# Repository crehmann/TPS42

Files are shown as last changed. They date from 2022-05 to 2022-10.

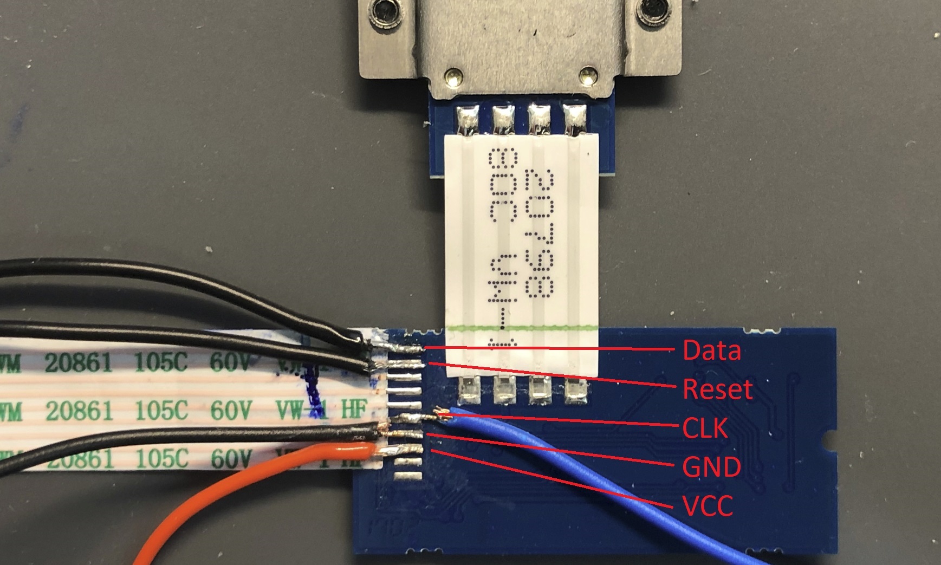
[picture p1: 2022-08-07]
Assets/trackpoint_wiring.jpg

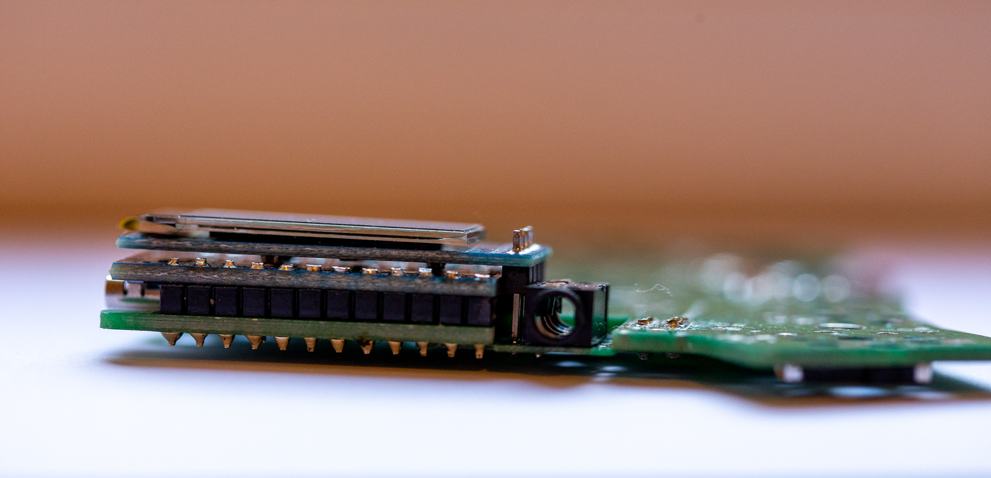
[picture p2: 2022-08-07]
Assets/wired_pcb_side.jpg

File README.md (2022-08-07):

# TPS42

TPS42 is a 42/36 keys ergonomic split keyboard. The outer pinky columns can be broken off. The main goal for desing it was to have a low profile split keyboard with an integrated TrackPoint module

## Features
- Integrated TrackPoint reset circuit and the option to mount a TrackPoint to the bottom of the PCB (between the two inner columns)
- I2C interface for an OLED display
- Wireless Ready (however, without TrackPoint support):
  - Battery switch / connector
  - Option to use a battery friendly Sharp memory display instead of an OLED display
- Choc-spaced
- Partially hot swap sockets supported (except for two switches around the TrackPoint module)

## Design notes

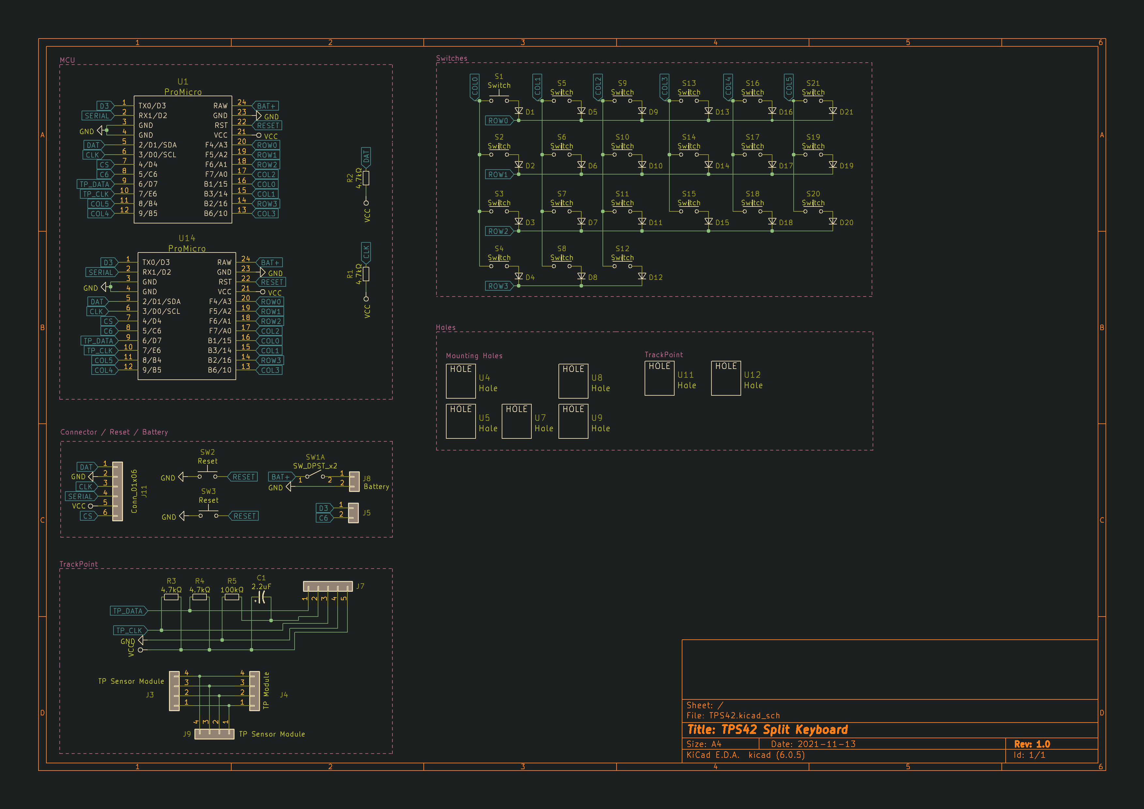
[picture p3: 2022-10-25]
Assets/schematic.png

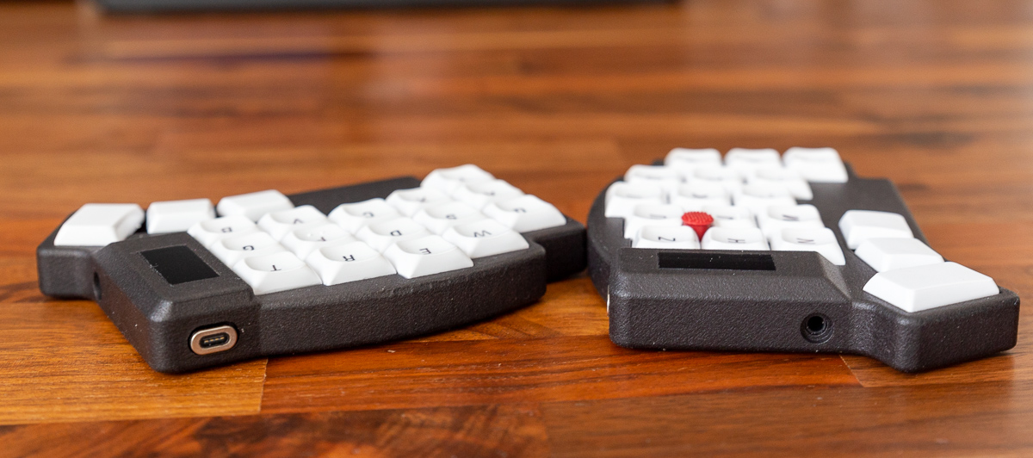
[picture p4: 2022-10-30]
Assets/wired_case_side.jpg

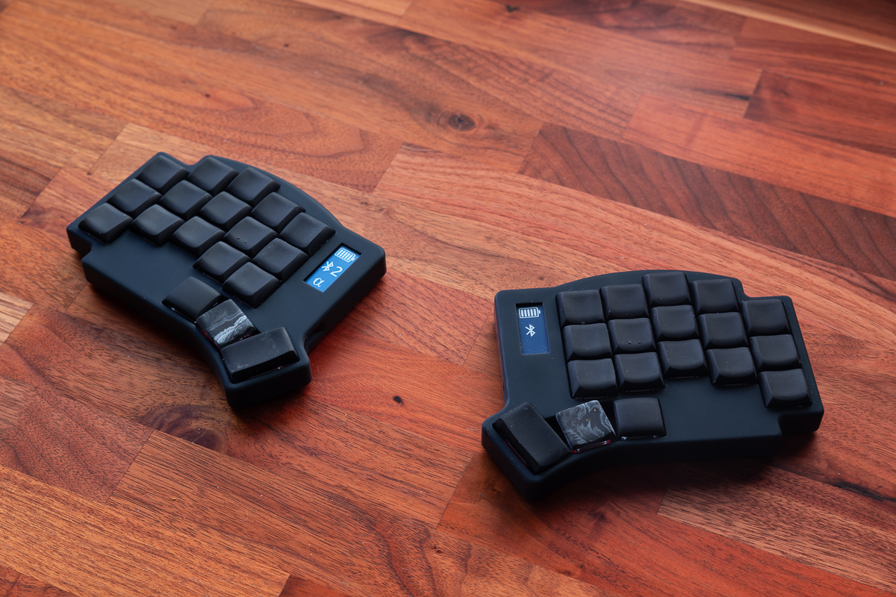
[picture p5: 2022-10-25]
Assets/wireless_case_top2.jpg

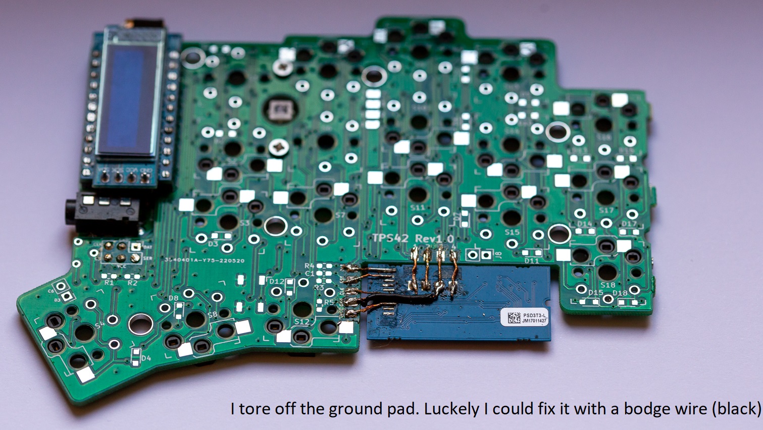
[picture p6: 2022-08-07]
Assets/wired_pcb_front.jpg

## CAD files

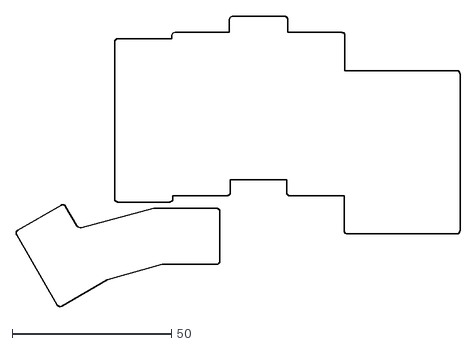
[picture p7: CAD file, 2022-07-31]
Case/3dp/outlines/keycaps_outline_3x6.dxf
139.3 x 91.2

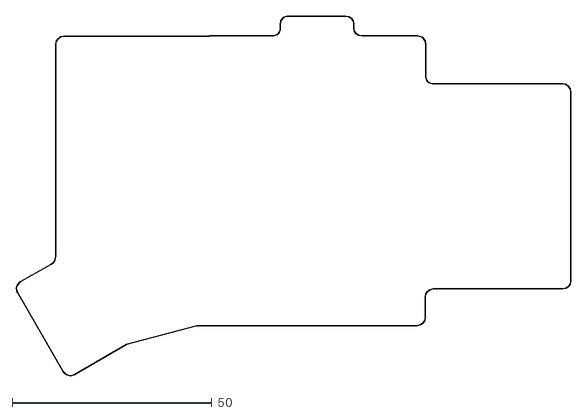
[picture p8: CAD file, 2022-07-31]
Case/3dp/outlines/pcb_outline_3x6.dxf
139.0 x 90.2

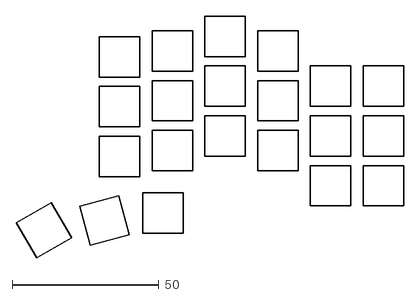
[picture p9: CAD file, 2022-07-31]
Case/3dp/outlines/switch_outline_3x6.dxf
132.1 x 82.5

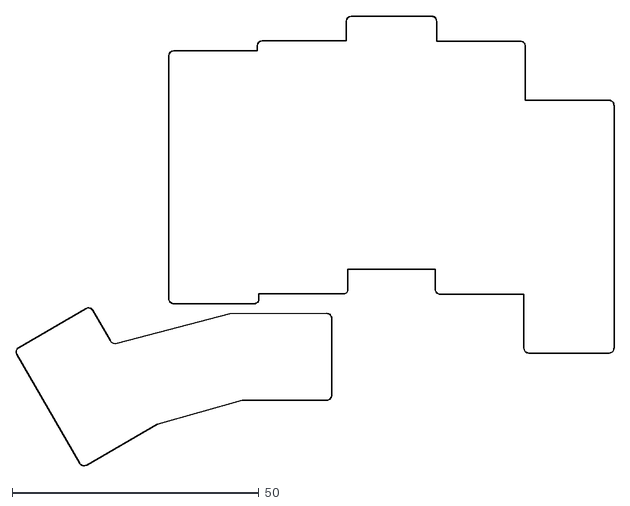
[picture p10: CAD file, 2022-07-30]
Case/3dp/outlines/keycaps_outline.dxf
121.2 x 91.2

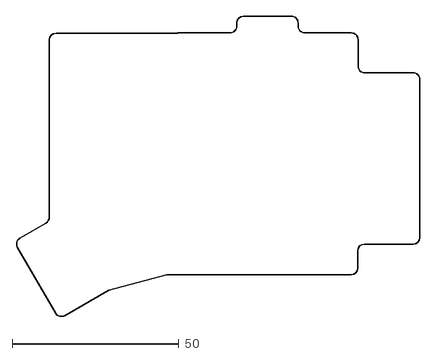
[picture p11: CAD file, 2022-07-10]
Case/3dp/outlines/pcb_outline.dxf
121.1 x 90.2

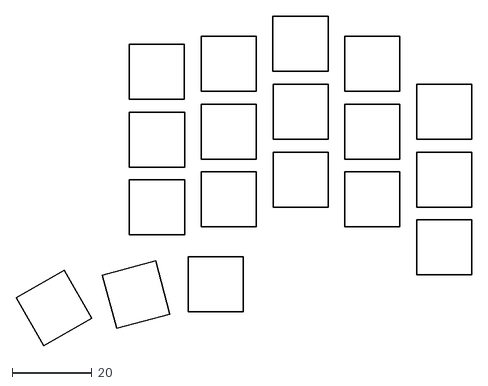
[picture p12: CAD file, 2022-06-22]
Case/3dp/outlines/switch_outline.dxf
114.2 x 82.5

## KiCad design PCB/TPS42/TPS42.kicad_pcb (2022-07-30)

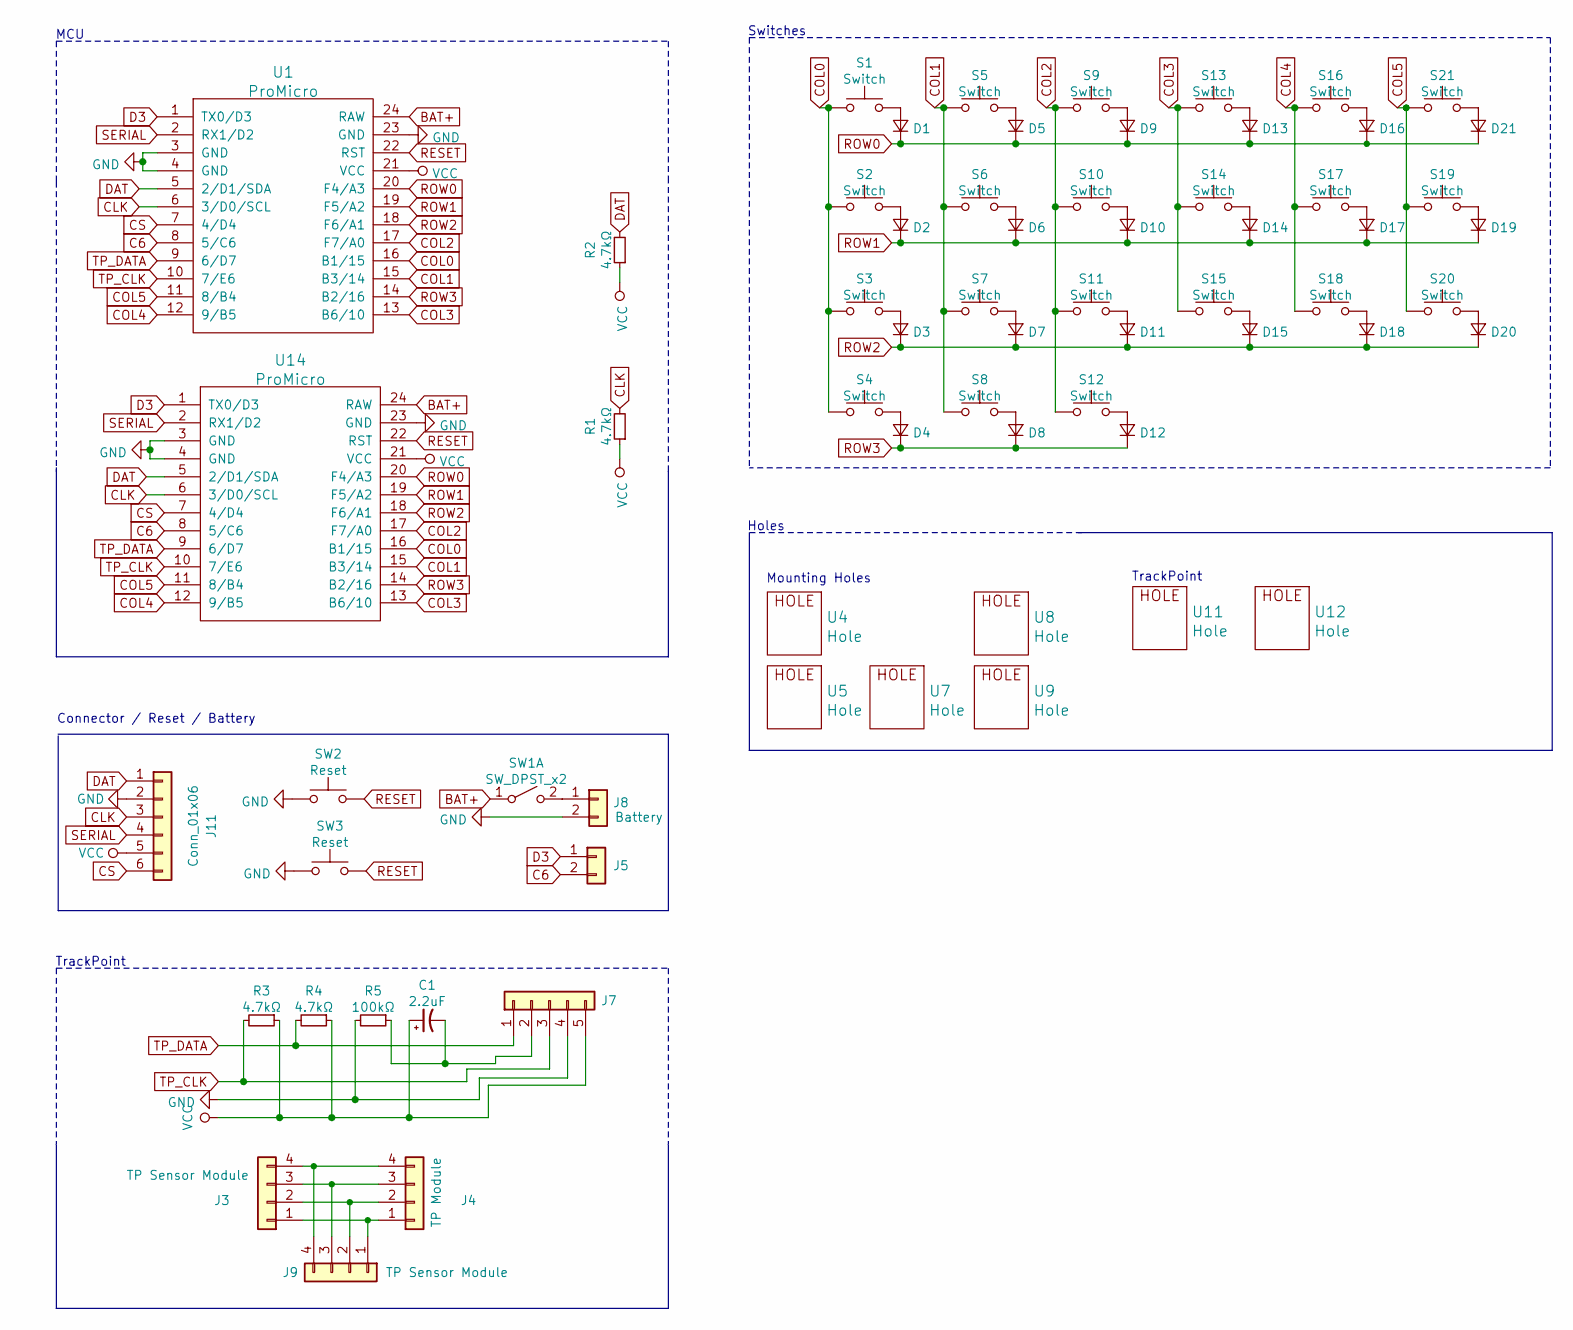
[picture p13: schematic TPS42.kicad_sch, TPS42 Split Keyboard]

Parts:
C1: 2.2uF; C_0603_1608Metric_Pad1.08x0.95mm_HandSolder_Reversable
D1, D2, D3, D4, D5, D6, D7, D8, D9, D10, D11, D12, D13, D14, D15, D16, D17, D18, D19, D20, D21: D_Small; D_SOD-323_HandSoldering_Reversable
J3, J9: TP Sensor Module; TPSensorModule_Connector
J4: TP Module; TPSensorModule_Connector
J5: Conn_01x02; PinHeader_1x02_P2.54mm_Vertical
J7: TrackPoint; TPModule
J8: Battery; PinHeader_1x02_P2.54mm_Vertical
J11: Conn_01x06; PinHeader_2x03_P2.54mm_Vertical
R1, R2, R3, R4: 4.7kΩ; R_0603_1608Metric_Pad0.98x0.95mm_HandSolder_Reversable
R5: 100kΩ; R_0603_1608Metric_Pad0.98x0.95mm_HandSolder_Reversable
S1, S6: Switch; SW_PG1350_reversible
S2, S3, S5, S7, S8, S9, S10, S11, S12, S13, S14, S15, S16, S17, S18, S19, S20, S21: Switch; Kailh_socket_PG1350_optional_reversible.kicad_mod
S4: Switch; Kailh_socket_PG1350_125_optional_reversible.kicad_mod
SW1: SW_DPST_x2; SW-TH_3P-L9.1-W3.5-P2.50-S3.20-A3
SW2, SW3: Reset; SMD-SW-4_5.1x5.1x2.5
U1: ProMicro; ProMicro_Flipped_v2_A
U4, U5, U7, U8, U9, U12: Hole; HOLE_M2_TH
U11: Hole; TPSensorModule
U14: ProMicro; ProMicro_Flipped_v2_B

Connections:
BAT+: SW1.1 (A), U1.24 (RAW), U14.24 (RAW)
C6: J5.2, U1.8 (5/C6), U14.8 (5/C6)
CLK: J11.3, R1.2, U1.6 (3/D0/SCL), U14.6 (3/D0/SCL)
COL0: S1.1, S2.1, S3.1, S4.1, U1.16 (B1/15), U14.16 (B1/15)
COL1: S5.1, S6.1, S7.1, S8.1, U1.15 (B3/14), U14.15 (B3/14)
COL2: S9.1, S10.1, S11.1, S12.1, U1.17 (F7/A0), U14.17 (F7/A0)
COL3: S13.1, S14.1, S15.1, U1.13 (B6/10), U14.13 (B6/10)
COL4: S16.1, S17.1, S18.1, U1.12 (9/B5), U14.12 (9/B5)
COL5: S19.1, S20.1, S21.1, U1.11 (8/B4), U14.11 (8/B4)
CS: J11.6, U1.7 (4/D4), U14.7 (4/D4)
D3: J5.1, U1.1 (TX0/D3), U14.1 (TX0/D3)
DAT: J11.1, R2.2, U1.5 (2/D1/SDA), U14.5 (2/D1/SDA)
GND: J7.4, J8.2, J11.2, R5.2, SW2.1, SW3.1, U1.3 (GND), U1.4 (GND), U1.23 (GND), U14.3 (GND), U14.4 (GND), U14.23 (GND)
unnamed: C1.2, J7.2, R5.1
unnamed: D1.2 (A), S1.2
unnamed: D2.2 (A), S2.2
unnamed: D3.2 (A), S3.2
unnamed: D4.2 (A), S4.2
unnamed: D5.2 (A), S5.2
unnamed: D6.2 (A), S6.2
unnamed: D7.2 (A), S7.2
unnamed: D8.2 (A), S8.2
unnamed: D9.2 (A), S9.2
unnamed: D10.2 (A), S10.2
unnamed: D11.2 (A), S11.2
unnamed: D12.2 (A), S12.2
unnamed: D13.2 (A), S13.2
unnamed: D14.2 (A), S14.2
unnamed: D15.2 (A), S15.2
unnamed: D16.2 (A), S16.2
unnamed: D17.2 (A), S17.2
unnamed: D18.2 (A), S18.2
unnamed: D19.2 (A), S19.2
unnamed: D20.2 (A), S20.2
unnamed: D21.2 (A), S21.2
unnamed: J3.1, J4.1, J9.1
unnamed: J3.2, J4.2, J9.2
unnamed: J3.3, J4.3, J9.3
unnamed: J3.4, J4.4, J9.4
unnamed: J8.1, SW1.2 (B)
RESET: SW2.2, SW3.2, U1.22 (RST), U14.22 (RST)
ROW0: D1.1 (K), D5.1 (K), D9.1 (K), D13.1 (K), D16.1 (K), D21.1 (K), U1.20 (F4/A3), U14.20 (F4/A3)
ROW1: D2.1 (K), D6.1 (K), D10.1 (K), D14.1 (K), D17.1 (K), D19.1 (K), U1.19 (F5/A2), U14.19 (F5/A2)
ROW2: D3.1 (K), D7.1 (K), D11.1 (K), D15.1 (K), D18.1 (K), D20.1 (K), U1.18 (F6/A1), U14.18 (F6/A1)
ROW3: D4.1 (K), D8.1 (K), D12.1 (K), U1.14 (B2/16), U14.14 (B2/16)
SERIAL: J11.4, U1.2 (RX1/D2), U14.2 (RX1/D2)
TP_CLK: J7.3, R3.2, U1.10 (7/E6), U14.10 (7/E6)
TP_DATA: J7.1, R4.2, U1.9 (6/D7), U14.9 (6/D7)
VCC: C1.1, J7.5, J11.5, R1.1, R2.1, R3.1, R4.1, U1.21 (VCC), U14.21 (VCC)

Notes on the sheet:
Holes
TrackPoint
Connector / Reset / Battery
Mounting Holes
Switches
MCU

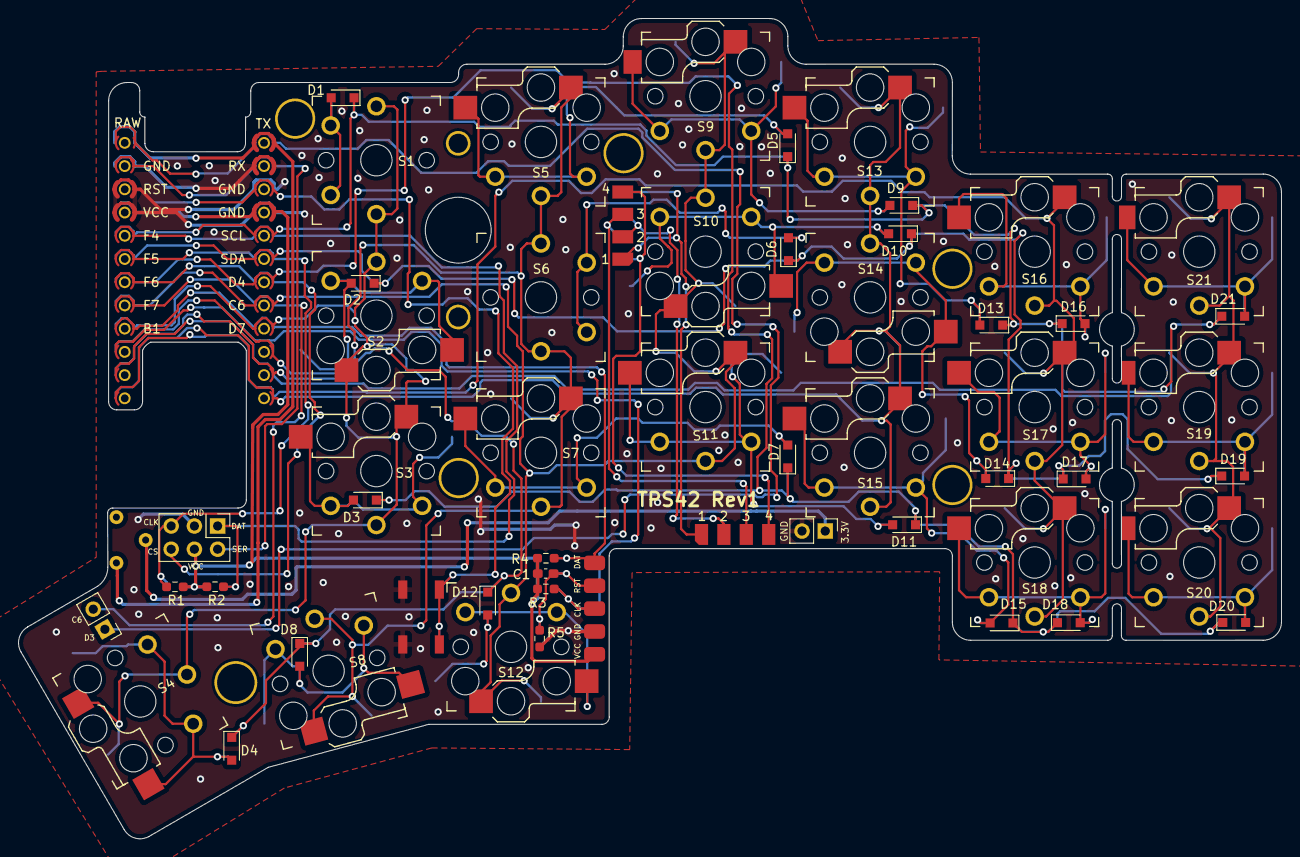
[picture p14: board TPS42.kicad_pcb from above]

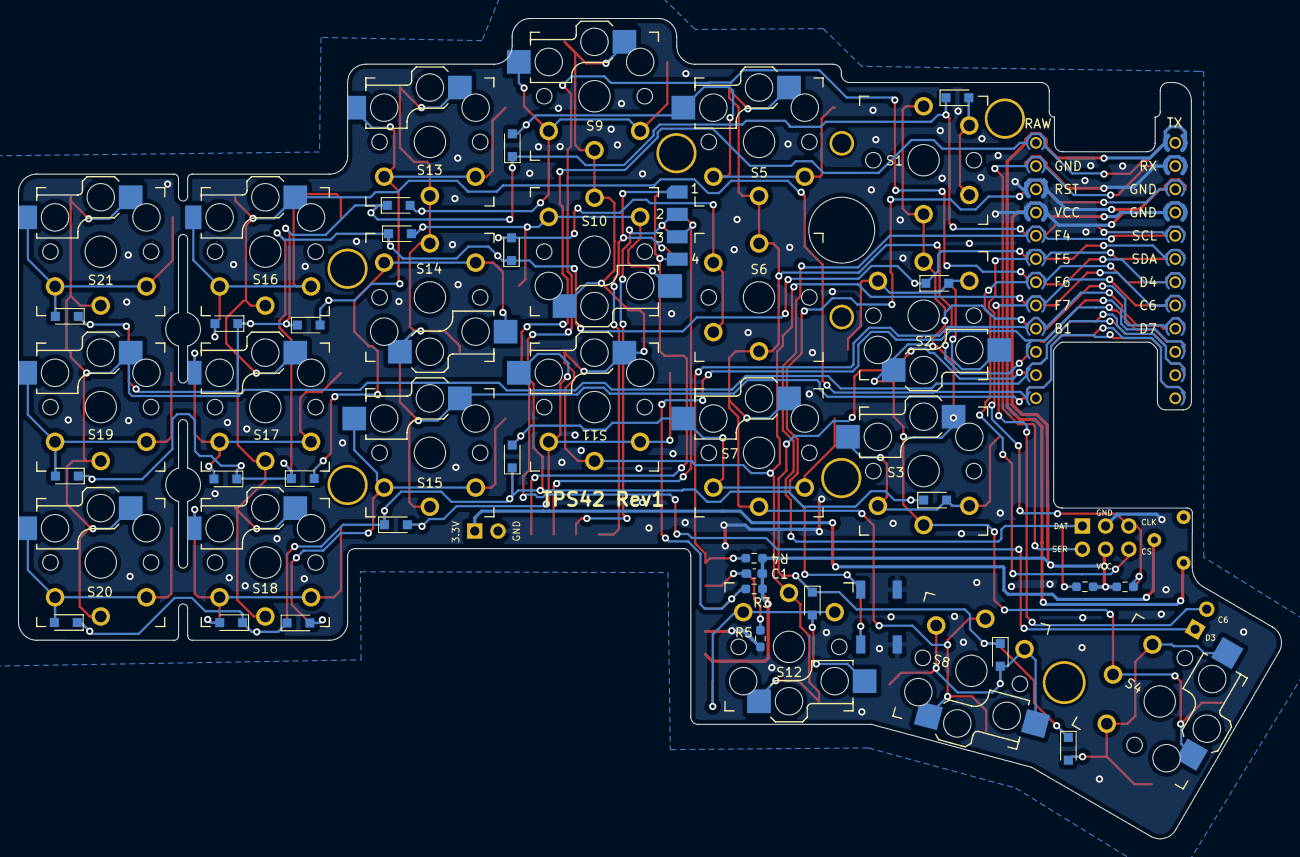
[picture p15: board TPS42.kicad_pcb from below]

Board: 2 copper layers, 138.1 x 89.7 mm, 67 parts (4 on the bottom side), 49 nets.

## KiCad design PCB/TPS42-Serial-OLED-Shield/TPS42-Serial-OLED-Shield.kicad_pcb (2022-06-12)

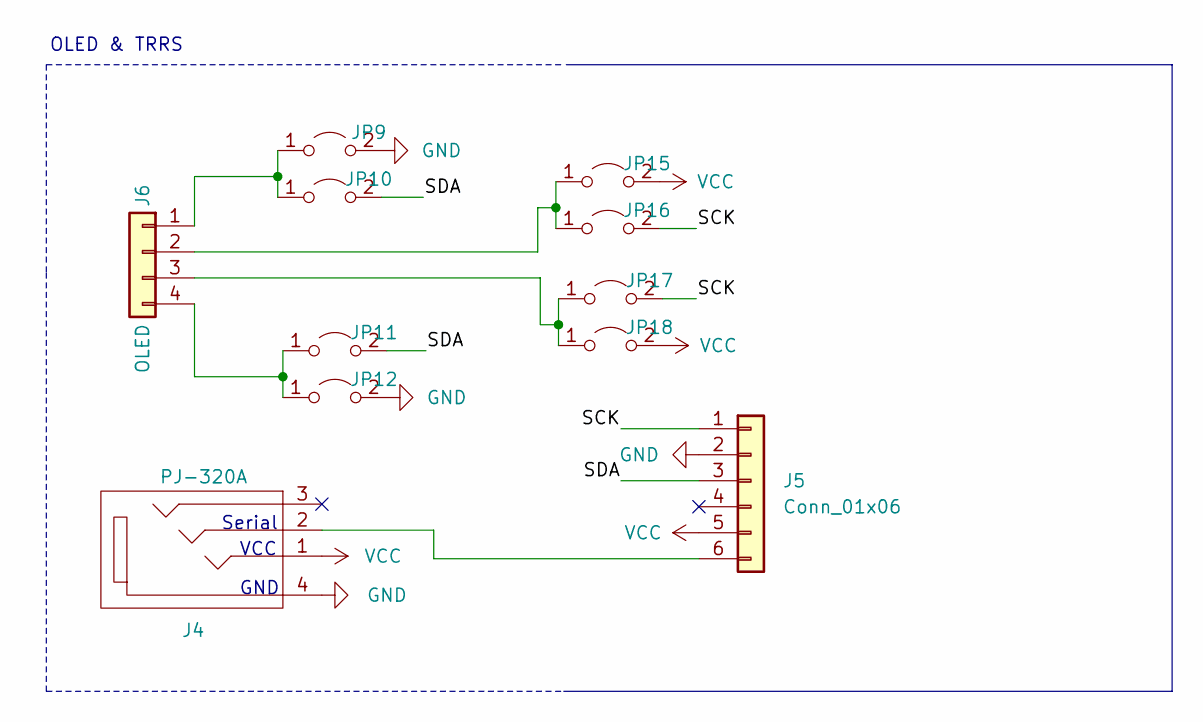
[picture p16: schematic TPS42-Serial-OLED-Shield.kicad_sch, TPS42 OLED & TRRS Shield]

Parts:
J4: PJ-320A; MJ-4PP-9-reversable
J5: Conn_01x06; PinHeader_2x03_P2.54mm_Vertical
J6: OLED
JP9, JP10, JP11, JP12, JP15, JP16, JP17, JP18: Jumper_2_Open; SolderJumper-2_P1.3mm_Open_TrianglePad1.0x1.5mm

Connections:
/SCK: J5.1, JP16.2 (B), JP17.2 (B)
/SDA: J5.3, JP10.2 (B), JP11.2 (B)
GND: J4.4, J5.2, JP9.2 (B), JP12.2 (B)
unnamed: J4.2, J5.6
unnamed: J6.1, JP9.1 (A), JP10.1 (A)
unnamed: J6.2, JP15.1 (A), JP16.1 (A)
unnamed: J6.3, JP17.1 (A), JP18.1 (A)
unnamed: J6.4, JP11.1 (A), JP12.1 (A)
VCC: J4.1, J5.5, JP15.2 (B), JP18.2 (B)

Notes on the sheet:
Serial
OLED & TRRS
VCC
GND

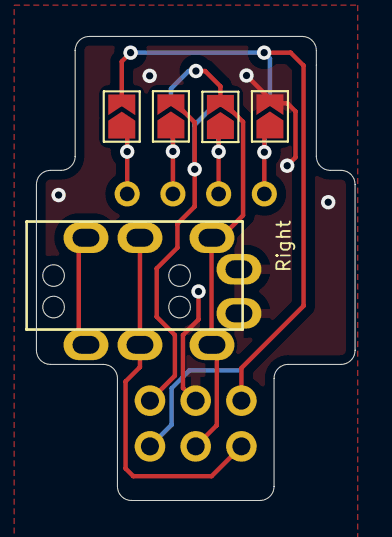
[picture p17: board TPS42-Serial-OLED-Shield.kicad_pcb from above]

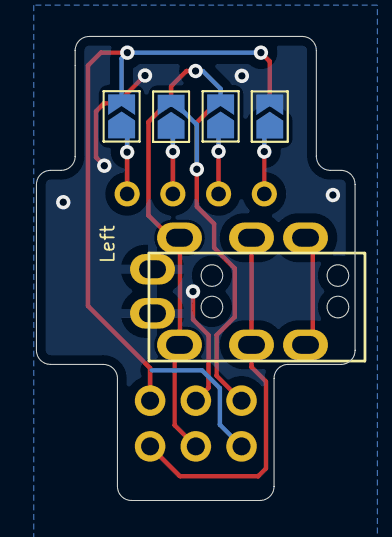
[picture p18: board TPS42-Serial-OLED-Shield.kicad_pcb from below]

Board: 2 copper layers, 17.7 x 25.8 mm, 11 parts (6 on the bottom side), 9 nets.

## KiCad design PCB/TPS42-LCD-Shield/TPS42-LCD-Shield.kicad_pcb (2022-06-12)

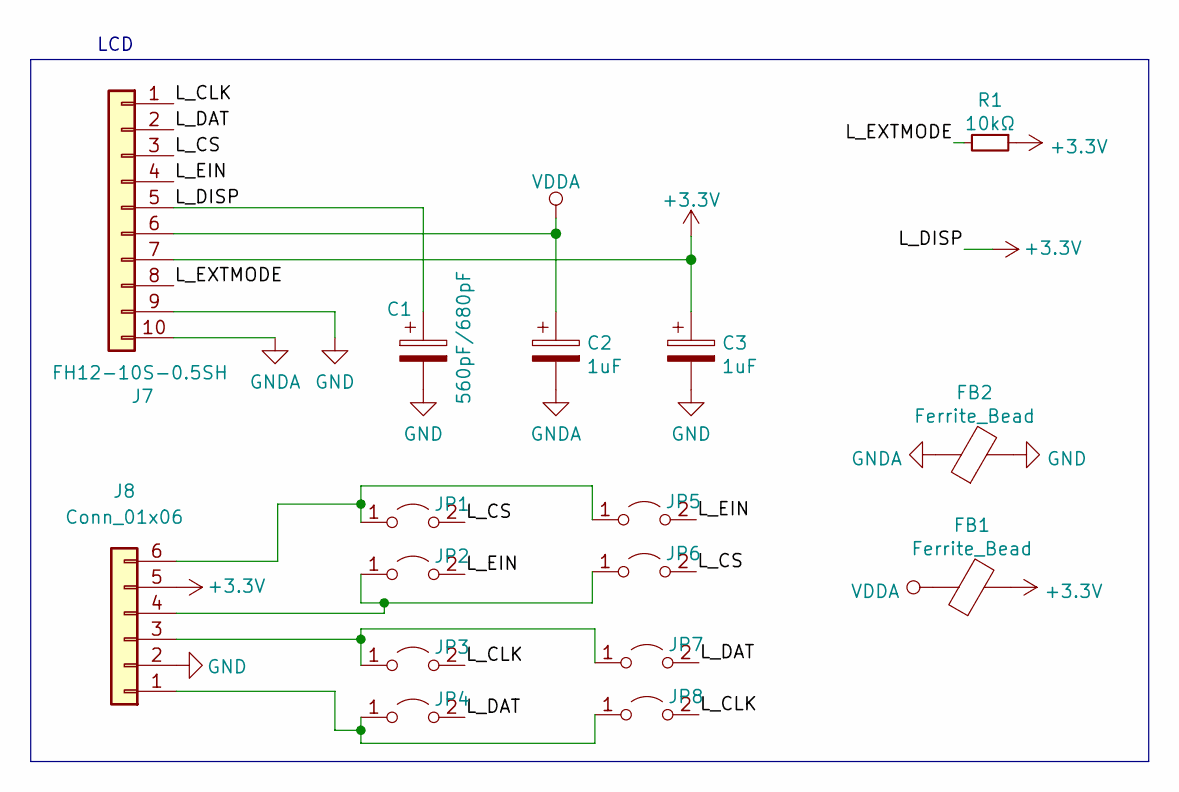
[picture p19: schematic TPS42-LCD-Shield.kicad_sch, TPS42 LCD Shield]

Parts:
C1: 560pF/680pF; C_0603_1608Metric_Pad1.08x0.95mm_HandSolder; LCSC C1630
C2, C3: 1uF; C_0603_1608Metric_Pad1.08x0.95mm_HandSolder; LCSC C15849
FB1, FB2: Ferrite_Bead; R_0805_2012Metric_Pad1.20x1.40mm_HandSolder; LCSC C1017
J7: FH12-10S-0.5SH; Hirose_FH12-10S-0.5SH_1x10-1MP_P0.50mm_Horizontal; LCSC C506791
J8: Conn_01x06; PinHeader_2x03_P2.54mm_Vertical
JP1, JP2, JP3, JP4, JP5, JP6, JP7, JP8: Jumper_2_Open; SolderJumper-2_P1.3mm_Open_TrianglePad1.0x1.5mm
R1: 10kΩ; R_0603_1608Metric_Pad0.98x0.95mm_HandSolder; LCSC C25804

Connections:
+3V3: C1.1, C3.1, FB1.2, J7.5, J7.7, J8.5, R1.1
/L_CLK: J7.1, JP3.2 (B), JP8.2 (B)
/L_CS: J7.3, JP1.2 (B), JP6.2 (B)
/L_DAT: J7.2, JP4.2 (B), JP7.2 (B)
/L_EIN: J7.4, JP2.2 (B), JP5.2 (B)
/L_EXTMODE: J7.8, R1.2
GND: C1.2, C3.2, FB2.2, J7.9, J8.2
GNDA: C2.2, FB2.1, J7.10
unnamed: J8.1, JP4.1 (A), JP8.1 (A)
unnamed: J8.3, JP3.1 (A), JP7.1 (A)
unnamed: J8.4, JP2.1 (A), JP6.1 (A)
unnamed: J8.6, JP1.1 (A), JP5.1 (A)
VDDA: C2.1, FB1.1, J7.6

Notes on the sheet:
LCD

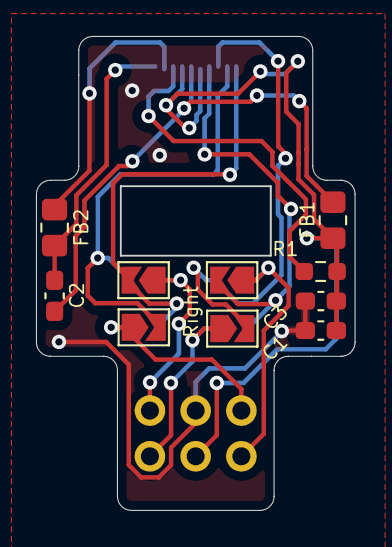
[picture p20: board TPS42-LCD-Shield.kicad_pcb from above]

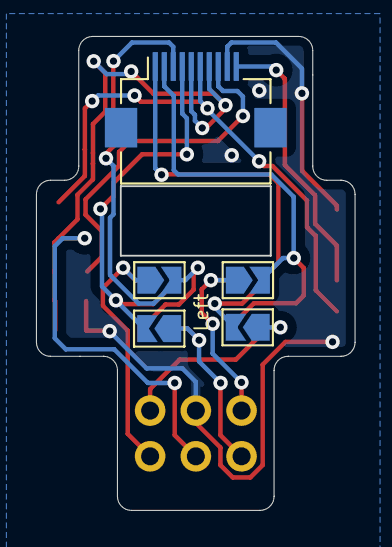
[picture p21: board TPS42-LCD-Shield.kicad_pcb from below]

Board: 2 copper layers, 17.7 x 26.3 mm, 16 parts (5 on the bottom side), 13 nets.

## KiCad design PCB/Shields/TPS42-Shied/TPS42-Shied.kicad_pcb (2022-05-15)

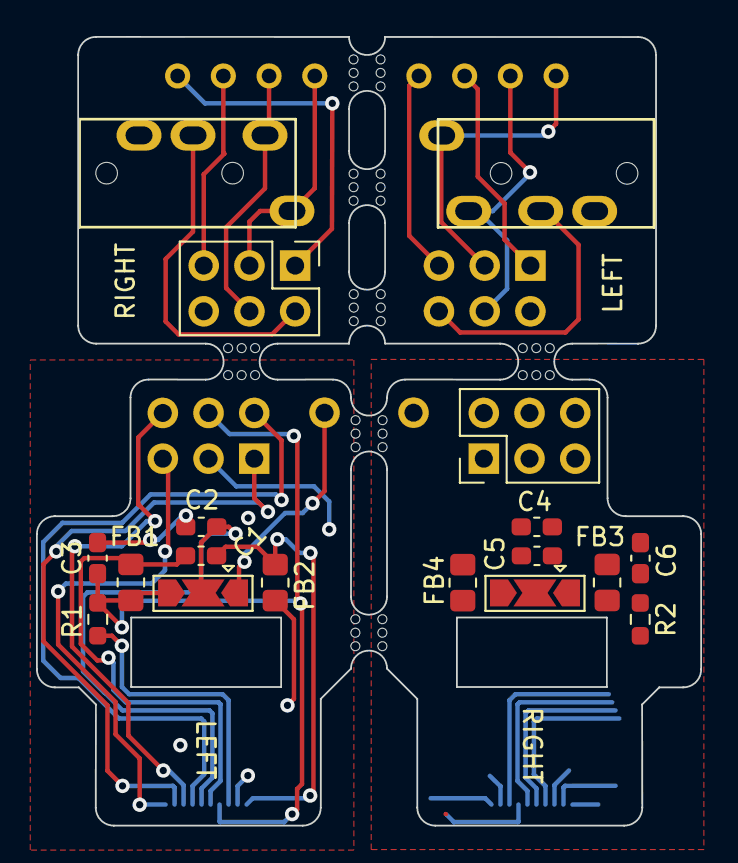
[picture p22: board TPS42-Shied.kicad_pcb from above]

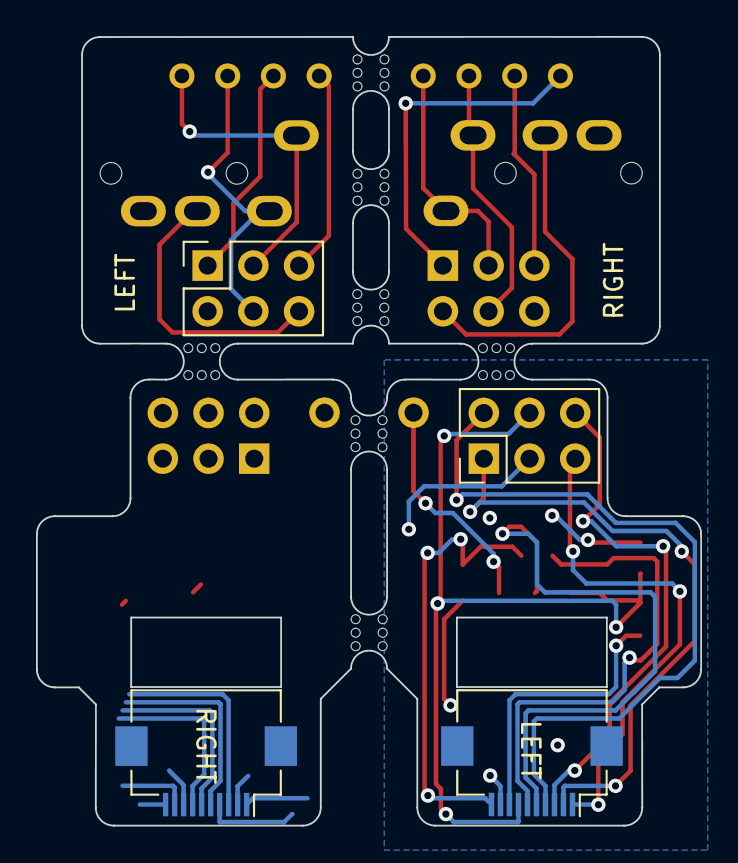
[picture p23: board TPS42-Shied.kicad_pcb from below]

Board: 2 copper layers, 36.9 x 43.8 mm, 33 parts (6 on the bottom side), 28 nets.

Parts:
C1, C4: 560pF/680pF; C_0603_1608Metric_Pad1.08x0.95mm_HandSolder
C2, C3, C5, C6: 1uF; C_0603_1608Metric_Pad1.08x0.95mm_HandSolder
FB1, FB2, FB3, FB4: Ferrite_Bead; R_0805_2012Metric_Pad1.20x1.40mm_HandSolder
J1, J4: PJ-320A; MJ-4PP-9
J2, J5, J8, J11: Conn_01x06; PinHeader_2x03_P2.54mm_Vertical
J3, J6: OLED
J7, J10: FH12-10S-0.5SH; Hirose_FH12-10S-0.5SH_1x10-1MP_P0.50mm_Horizontal
J9, J12: Conn_01x01; PinHeader_1x01_P2.54mm_Vertical
JP1, JP2: Jumper_3_Open; SolderJumper-3_P2.0mm_Open_TrianglePad1.0x1.5mm
R1, R2: 10kΩ; R_0603_1608Metric_Pad0.98x0.95mm_HandSolder
mouse-bite-2mm-slot, mouse-bite-2mm-slot#2, mouse-bite-2mm-slot#3, mouse-bite-2mm-slot#4, mouse-bite-2mm-slot#5, mouse-bite-2mm-slot#6, mouse-bite-2mm-slot#7: VAL**; mouse-bite-2mm-slot

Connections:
+3V3: C3.1, C6.1, FB1.2, FB3.2, J7.7, J8.5, J10.7, J11.5, JP1.3 (B), JP2.3 (B), R1.1, R2.1
/L_CLK: J7.1, J8.3
/L_CS: J7.3, J8.6
/L_DAT: J7.2, J8.1
/L_DISP: C1.1, J7.5, JP1.2 (C)
/L_EIN: J7.4, J8.4
/L_EXTMODE: J7.8, R1.2
/R_CLK: J10.1, J11.3
/R_CS: J10.3, J11.6
/R_DAT: J10.2, J11.1
/R_DISP: C4.1, J10.5, JP2.2 (C)
/R_EIN: J10.4, J11.4
/R_EXTMODE: J10.8, R2.2
GND: C1.2, C3.2, C4.2, C6.2, FB2.2, FB4.2, J7.9, J8.2, J10.9, J11.2
GNDA: C2.2, C5.2, FB2.1, FB4.1, J7.10, J10.10
unnamed: J1.1, J2.5, J3.3
unnamed: J1.2, J2.4
unnamed: J1.4, J2.2, J3.4
unnamed: J2.1, J3.1
unnamed: J2.3, J3.2
unnamed: J4.1, J5.5, J6.3
unnamed: J4.2, J5.4
unnamed: J4.4, J5.2, J6.4
unnamed: J5.1, J6.1
unnamed: J5.3, J6.2
unnamed: J9.1, JP1.1 (A)
unnamed: J12.1, JP2.1 (A)
VDDA: C2.1, C5.1, FB1.1, FB3.1, J7.6, J10.6

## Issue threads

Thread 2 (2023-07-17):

unused vias, shields

idank, 2023-07-17:
Hey, thanks for opening the issue tracker! I'm looking into your keyboard, nice design.

I'd like to change it to use the integrated trackpoint pcb, and I was just studying your pcb and had these questions:

1. there are a lot of unused vias, what's up with that?
2. do i understand correctly that the lcd/oled shields exist solely to have the option to choose one or the other, while keeping the main pcb the same?

crehmann, 2023-07-17:
Hi!
Thank you and I am happy to hear that it interests you.

1. Do you mean the vias that are connecting the ground fill? I used on the top and bottom side of the pcb a ground fill and added some vias to remove some islands

2. yes, exactly!

idank, 2023-07-19:
Ah interesting, thanks for answering. It took some time but I removed all of those and merged the OLED shield to the main pcb as I don't need the LCD one. Hope it all works out!

crehmann, 2023-07-22:
You are welcome & happy build!

idank, 2023-08-18:
Btw one issue I just noticed is that the diode direction isn't on the silk screen layers. I did my soldering with kicad open, but it might be good to fix that.

crehmann, 2023-08-20:
There are different symbols for diodes and each has its own way to display the orientation. The one I used indicates the orientation with the closed side of the rectangle:

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

idank, 2023-08-20:
Ah, didn't notice those, thanks!

crehmann, 2023-09-03:
No worries, let me know if you find any issues I can fix

Closed 2023-07-19.

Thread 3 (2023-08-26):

errror while creating case

viyoriya, 2023-08-26:
Hi loved the case thought to create one for cantor/piantor .
got this error while creating case and not much details in internet to fix the error.
Its creating bottom plate but not case.

OCP.StdFail.StdFail_NotDone: BRep_API: command not done

crehmann, 2023-09-03:
Sorry, did not see your issue. Did you resolve it? The error itself does not say anything to me..

Closed 2023-08-29.

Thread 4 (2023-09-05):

I want to ues nice!nano to make the wireless version,how should I do?

Alohaq, 2023-09-05:
I was immediately drawn to this keyboard, so I embarked on my first experience of building a ZMK keyboard. Initially, I tried to compile the tps42 keyboard configuration from the ARM folder, but it didn't work as expected. Then, I replaced the "arduino_pro_micro_pins.dtsi" file with the one from the "nicenano" folder. After that, I ran the command "west build -b tps42_left" and flashed the firmware. However, it seems that the keyboard is not functioning correctly.

crehmann, 2023-09-06:
Hi,
Yes it is possible to use a nice!nano (I am using a nrfMicro). I used a custom ARM configuration to have custom code for the custom widgets. There you would also need to update the tps42-pinctrl.dtsi and tps42.dtsi.  A nice pinout can be found here to see which pins are different: https://github.com/joric/nrfmicro/wiki/Pinout

Another option would be to create a shield instead of an ARM board configuration. Creating a shield may be simpler and there is a documentation from ZMK: https://zmk.dev/docs/development/new-shield

Alohaq, 2023-09-11:
Hi,
According to your instructions, I made changes to tps42.dtsi and tps42-pinctrl.dtsi. However, I have only implemented the left-hand side so far. Some keys are triggering incorrectly, and the bottom-left corner (identified as Caps Lock in the keymap) is not being triggered. I noticed a voltage drop of 1.9V across the diode at both ends. Additionally, when I measured the LCD side, the voltage was only around 0.4V. What could be causing these issues?

Alohaq, 2023-09-11:
Just now, I changed the enable level of External VCC, and luckily, the LCD lit up successfully. Now, there are only two remaining issues: when pressing the Z key, sometimes it triggers the Windows key, and it happens quite frequently. I suspect there might be an issue with a certain diode. I'm getting closer to success. The other issue is that Caps Lock is not functioning.

crehmann, 2023-09-19:
Do you use caps lock on a certain switch and is the switch not working in general or is it only the caps lock key?

hunterwei, 2024-02-22:
> Hi, Yes it is possible to use a nice!nano (I am using a nrfMicro). I used a custom ARM configuration to have custom code for the custom widgets. There you would also need to update the tps42-pinctrl.dtsi and tps42.dtsi. A nice pinout can be found here to see which pins are different: https://github.com/joric/nrfmicro/wiki/Pinout
>
> Another option would be to create a shield instead of an ARM board configuration. Creating a shield may be simpler and there is a documentation from ZMK: https://zmk.dev/docs/development/new-shield

For other TPS42 lovers' convenience, I made a tps42-config repo that using the shield approach to support nice!nano MCU, please feel free to use https://github.com/hunterwei/tps42-config

crehmann, 2024-05-22:
@hunterwei Thank you for the config. I link to it in the wiki.

Closed 2024-05-31.

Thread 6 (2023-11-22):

Disassembly of the trackpoint

jonasherr, 2023-11-22:
Thank you for the great resources 🙏

I just got all the parts for my build and two old lenovo thinkpads.
Do have any tips or documentation for removing the trackpoint from a thinkpad keyboard?
I just found these two screws that I could remove, but now I am unsure how to proced without damaging the keyboard and the trackpoint.

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

jonasherr, 2023-11-22:
Moved to discussion: https://github.com/crehmann/TPS42/discussions/7

Closed 2023-11-22.

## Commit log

2022-05-08 Initial copy from buzzard
    [TPS42.kicad_pcb, TPS42.kicad_sch]
2022-05-08 align footprints
    [TPS42.kicad_pcb, TPS42.kicad_sch]
2022-05-08 fix switch orientation
    [TPS42.kicad_pcb]
2022-05-08 Footprint library cleanup
    [TPS42.kicad_pcb]
2022-05-08 Further footprint changes
    [TPS42.kicad_pcb, TPS42.kicad_sch]
2022-05-09 replaced diode footprint
    [TPS42.kicad_pcb, TPS42.kicad_sch]
2022-05-09 breakoff column added
    [TPS42.kicad_pcb]
2022-05-09 connected tp module
    [TPS42.kicad_pcb]
2022-05-09 place components
    [TPS42.kicad_pcb]
2022-05-09 mcu bridges
    [TPS42.kicad_pcb, TPS42.kicad_sch]
2022-05-09 Setting some labels
    [TPS42.kicad_pcb]
2022-05-10 started routing
    [TPS42.kicad_pcb, TPS42.kicad_sch]
2022-05-11 connect all mcu pins
    [TPS42.kicad_pcb, TPS42.kicad_sch]
2022-05-11 more routing
    [TPS42.kicad_pcb]
2022-05-12 and more routing
    [TPS42.kicad_pcb]
2022-05-14 and even more routing
    [TPS42.kicad_pcb]
2022-05-14 finished main pcb routing
    [TPS42.kicad_pcb, TPS42.kicad_sch]
2022-05-14 Added oled/trrs shield
    [TPS42-Shied.kicad_pcb, TPS42-Shied.kicad_sch, TPS42.kicad_pcb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]
2022-05-15 add left lcd shield
    [TPS42-Shied.kicad_pcb, TPS42-Shied.kicad_sch]
2022-05-15 fixed typo
    [TPS42-Shiedl.kicad_pcb, TPS42-Shield.kicad_sch]
2022-05-16 finish routing
    [TPS42-Shiedl.kicad_pcb]
2022-05-17 ignore gerber zips
2022-05-17 fix renaming
    [TPS42-Shield.kicad_pcb]
2022-05-17 center shield pins with mcu
    [TPS42.kicad_pcb]
2022-05-17 make it reversable (I)
    [TPS42-Shield.kicad_pcb, TPS42-Shield.kicad_sch, TPS42.kicad_pcb]
2022-05-18 splitted shields
    [TPS42-LCD-Shield.kicad_pcb, TPS42-LCD-Shield.kicad_sch, TPS42-Shield.kicad_pcb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]
2022-06-12 reduced with and added longer pads for fcc
    [TPS42-LCD-Shield-B_Cu.gbr, TPS42-LCD-Shield-B_Mask.gbr, TPS42-LCD-Shield-B_Paste.gbr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]
2022-06-12 removed serial jumber
    [TPS42-Serial-OLED-Shield.kicad_pcb, TPS42-Serial-OLED-Shield.kicad_sch]
2022-06-15 add case outlines
    [TPS42.kicad_pcb]
2022-06-22 added outlines
    [TPS42.kicad_pcb]
2022-06-22 add labels for battery connection
    [TPS42.kicad_pcb]
2022-06-22 started with case design
    [keycaps_outline.dxf, pcb_outline.dxf, switch_outline.dxf]
2022-06-24 add cutouts for mcu and connectors
    [TPS42.kicad_pcb]
2022-06-24 prepare bottom plate
2022-06-25 add cutout for track point module and finalize bottom plate
2022-06-25 improved switch cutout
2022-06-25 added helper points
    [TPS42.kicad_pcb]
2022-06-26 reduced indentation for shield solder points
2022-07-05 fix lcd extrusion height and add additional cutouts around top plate
    [TPS42.kicad_pcb]
2022-07-07 work on wireless case
    [TPS42.kicad_pcb, keycaps_outline.dxf]
2022-07-10 fix usb c connector offset for wireless case and some wall thickness improvements
    [TPS42.kicad_pcb, pcb_outline.dxf]
2022-07-24 improved wireless case power switch hole and removed display extrusion
2022-07-30 moved lcd cutout a little down and increased thumb 1.5 outline
    [TPS42.kicad_pcb, keycaps_outline.dxf]
2022-07-31 Add fr4 top plate
    [TPS42.kicad_pcb]
2022-07-31 Added FR4 Bottom Plate
    [TPS42.kicad_pcb]
2022-07-31 moved dxf files into sub directory
    [keycaps_outline.dxf, keycaps_outline_3x6.dxf, pcb_outline.dxf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]
